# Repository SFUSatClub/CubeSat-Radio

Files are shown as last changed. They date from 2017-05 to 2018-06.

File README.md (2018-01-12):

# CubeSat-Radio
KiCad project of the cubesat radio test article in preparation for the Canadian Satellite Design Challenge

This repository uses the SFU Satellite Team's KiCad component library as a submodule.
To start working on the repository:

```
1. Open the git shell
2. Navigate to the directory you wish to place the repository inside
3. git clone --recursive "https://github.com/SFUSatClub/CubeSat-Radio.git"
4. cd .\CubeSat-Radio\KiCad-Lib\
5. git checkout master
```

If you modify either the component schematic or footprint libraries you must push those changes to the SFUSatClub/KiCad-Lib repository.

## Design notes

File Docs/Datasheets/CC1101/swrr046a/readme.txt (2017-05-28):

   
XXXXXXXXXXXXXXXXXXXXXXXXXXXXXXXXXXXXXXXXXXXXXXXXXXXXXXXXXXXXXXXXXXXXXXXXXXXXX
X                                                                           X
X   Artwork and documentation done by: Texas Instrument                     X
X                                                                           X
X   Company: Texas Instrument Norway Gaustadalleen 21    0349 OSLO          X
X                                                                           X
X   Phone  : +47 22 95 85 44   Fax :  +47 22 95 85 46                       X
X                                                                           X
X                                                                           X
XXXXXXXXXXXXXXXXXXXXXXXXXXXXXXXXXXXXXXXXXXXXXXXXXXXXXXXXXXXXXXXXXXXXXXXXXXXXX

PROJECT : 02552
PCB NAME : CC1101EM 434MHz
REVISION: 2.0.0 (schematic rev 2.0.0, PCB rev 2.0.0)
DATE: 2010-02-15

Manufacturers marking: Two letter + year + week
The two letter code shall identify the manufaturer and is decided by the manufacturer. 
No logos or other identifyers are allowed.
The marking shall be in silk screen print at secondary side of the PCB, or in solder 
resist if no silk print at secondary side.

FILE: CC1101EM_434MHz_2_0_0.ZIP PACKED WITH WinZIP 

PCB DESCRIPTION: 2 LAYER PCB 0.8 MM NOMINAL THICKNESS FR4
		Dimensions in mil (0.001 inch)
                            DOUBLE SIDE SOLDER MASK,
                            DOUBLE SIDE SILKSCREEN,
                            8 MIL MIN TRACE WIDTH AND 8 MIL MIN ISOLATION
		Dielectric constant for FR4 is 4.5

FILE NAME            		DESCRIPTION                               	FILE TYPE
-------------------------------------------------------------------------------------------
***PCB MANUFACTURING FILES:
l1.SPL                  LAYER 1 COMPONENT SIDE/POSITIV              EXT. GERBER
l2.SPL                  LAYER 2 Inner layer/POSITIV                 EXT. GERBER

STOPCOMP.SPL            SOLDER MASK COMPONENT SIDE/NEGATIVE         EXT. GERBER
STOPSOLD.SPL            SOLDER MASK SOLDER SIDE/NEGATIVE            EXT. GERBER

SILKCOMP.SPL            SILKSCREEN COMPONENT SIDE/POSITIVE          EXT. GERBER
SILKSOLD.SPL            SILKSCREEN SOLDER SIDE/POSITIVE             EXT. GERBER

PASTCOMP.SPL            SOLDER PAST COMPONENT SIDE/POSITIVE         EXT. GERBER
PATSOLD.SPL             SOLDER PAST SOLDER SIDE/POSITIVE            EXT. GERBER

ASSYCOMP.SPL            ASSEMBLY DRAWING COMPONENT SIDE					    EXT. GERBER
ASSYSOLD.SPL            ASSEMBLY DRAWING SOLDER SIDE				|       EXT. GERBER

NCDRILL.SPL             NC DRILL THROUGH HOLE                       EXCELLON
DRILL.SPL               DRILL/MECHANICAL DRAWING                    EXT. GERBER

GERBER.REP              DRILL/NC DRILL REPORT                       ASCII

P&PCOMP.REP             PICK AND PLACE FILE COMPONENT SIDE          ASCII
P&PSOLD.REP             PICK AND PLACE FILE SOLDER SIDE             ASCII

EXT_GERBER.USR          EXTENDED GERBER APERTURE TABLE              ASCII
CNC.USR                 NC DRILL DEVICE FILE                        ASCII

CC1100EM_868_915MHz_PARTLIST_2_0_0.xls		PART LIST									ASCII

***PDF FILES:
CC1101EM_868_915MHz_SCHEMATIC_2_0_0.PDF	Circuit Diagram
CC1101EM_868_915MHz_LAYOUT_2_0_0.PDF		Layout Diagram

***CADSTAR FILES:
CC1101EM_868_915MHz_2_0_0.SCM			Cadstar Schematic file
CC1101EM_868_915MHz_2_0_0.CSA			Cadstar Shematic archive
CC1101EM_868_915MHz_2_0_0.PCB			Cadstar Layout file
CC1101EM_868_915MHz_2_0_0.CPA			Cadstar PCB archive

README.TXT              THIS FILE                                   ASCII

***REVISION HISTORY

Changes from rev 1.0 to 2.0.0: 
	Crystal X1 changed to size 3.2x2.5 mm (NX3225GA)
	Changed crystal loading capacitors C81 and C101 to 12 pF and 15 pF respectively

END.

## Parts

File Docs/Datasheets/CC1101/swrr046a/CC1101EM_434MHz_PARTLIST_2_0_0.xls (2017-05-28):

CC1101EM 434 MHz Partlist 2.0.0
This list is automatically linked up to the G:\06_TEKNISK\06H_Cadstar\purchase_library\PurchaseLib.xls
Enter columns in green
Ref. | Part name | Pcs/unit | Description | Manufacturer | Part number | Supplier | Ordering code | Alt. Manufacturer | Alt. Part number | Alt. Supplier | Alt. Ordering code | Comments
U1 | CC1101 | 1 | Single-chip transceiver | TI | CC1101 | TI | CC1101 |  |  |  |  | Supplied by Chipcon
C41;C51 | C_100N_0402_X5R_K_10 | 2 | Capacitor, 100n, 0402, X5R, 10%, 10V | Murata | GRM155R71A104KA01D
C91;C141 | C_10N_0402_X7R_K_25 | 2 | Capacitor, 10n, 0402, X7R, 10%, 25V | Murata | GRM155R71E103KA01D
C81 | C_12P_0402_NP0_J_50 | 1 | Capacitor, 12p, 0402, NP0, 5%, 50V | Murata | GRM1555C1H120JZ01D
C101 | C_15P_0402_NP0_J_50 | 1 | Capacitor, 15p, 0402, NP0, 5%, 50V | Murata | GRM1555C1H150JZ01D
C1 | C_1U_0805_X7R_K_16 | 1 | Capacitor, 1u, 0805, X7R, 10%, 16V | Murata | GRM21BR71C105KA01L | ELFA | 65-809-71
C111;C124-125;C151;C181 | C_220P_0402_NP0_J_50 | 5 | Capacitor, 220p, 0402, NP0, 5%, 50V | Murata | GRM1555C1H221JA01D
C121;C131 | C_3P9_0402_NP0_C_50 | 2 | Capacitor, 3p9, 0402, NP0, +-0.25pF, 50V | Murata | GRM1555C1H3R9CZ01D
C123 | C_5P6_0402_NP0_C_50 | 1 | Capacitor, 5p6, 0402, NP0, +-0.25pF, 50V | Murata | GRM1555C1H5R6CZ01D
C122 | C_8P2_0402_NP0_C_50 | 1 | Capacitor, 8p2, 0402, NP0, +-0.25pF, 50V | Murata | GRM1555C1H8R2CZ01D
L122 | L_22N_0402_J | 1 | Inductor, 22n, 0402, ±5% | Murata | LQG15HS22NJ02D | ACTE
L121;L123;L131 | L_27N_0402_J | 3 | Inductor, 27n, 0402, ±5% | Murata | LQG15HS27NJ02D | ACTE
L1 | L_BEAD_102_0402 | 1 | EMI filter bead, 0402 1Kohms Tape GHz Band Gen Use | Murata | BLM15HG102SN1D | ACTE
R171 | R_56K_0402_F | 1 | Resistor, 56k ohms, 0402, ±1% | Koa | RK73H1ETTP5602F | ELFA | 60-488-96
P3 | SMA_SMD | 1 | SMA connector, straight SMD-mount | Hus-Tsan Group Taiwan | SMA-10V21-TGG | EC Partner A/S | SMA-10V21-TGG
P1-2 | SMD_SOCKET_2x10 | 2 | SMD pinrow socket, .050 spacing, 2x10 | Samtec | SFM-110-02-SM-D-A-K-TR | Abacus
X1 | X_26.000/20/40/40/10 | 1 | Crystal, 26.000000MHz, 10.0pF, 50 ohms max, 20/40 ppm, -40C to +85C | NDK | NX3225GA, EXS00A-CG01972 | NDK | NX3225GA, EXS00A-CG01972
 |  | 27

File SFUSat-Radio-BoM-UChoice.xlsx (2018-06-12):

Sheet: SFUSat-Radio
Reference | Value | Footprint | Datasheet | Part Number | Digi-Key | Mouser | Digikey | Categories | Composition | Failure Rate | Features | Height - Seated (Max) | Lead Free Status / RoHS Status | Manufacturer 1 | Manufacturer Part Number 1 | Manufacturer Standard Lead Time 1 | Number of Terminations | Package / Case | Part Status | Power (Watts) | Resistance | Series | Size / Dimension | Supplier 1 | Supplier Device Package | Supplier Part Number 1 | Temperature Coefficient | Tolerance | Circuit | Frequency - Lower | Frequency - Upper | IIP3 | Impedance | Insertion Loss @ Frequency | Isolation @ Frequency | Operating Temperature | P1dB | RF Type | Topology | Voltage - Supply | Base Part Number | Current - Output High | Low | Independent Circuits | Mounting Type | Type | Voltage Supply Source | Applications | Capacitance | Lead Spacing | Lead Style | Ratings | Thickness (Max) | Voltage - Rated | Current Rating | DC Resistance (DCR) | Frequency - Self Resonant | Frequency - Test | Inductance
J1 | PC104-8BIT | SFUSat:PC104-8bit
J4 | PC104PTH | SFUSat:PC104PTH
J5 | PC104PTH | SFUSat:PC104PTH
J3 | PC104PTH | SFUSat:PC104PTH
J2 | PC104PTH | SFUSat:PC104PTH
C415 | DNP | SFUSat:C_0402
U1 | SINGLE_0402 | SFUSat:SINGLE_0402
U500 | SINGLE_0402 | SFUSat:SINGLE_0402
U400 | SINGLE_0402 | SFUSat:SINGLE_0402
R604 | DNP | SFUSat-res:R_0402
L503 | DNP | SFUSat-ind:L_0603
R2 | 1k0-DNP | SFUSat-res:R_0402 |  |  |  |  |  | Resistors - Chip Resistor - Surface Mount | Thin Film | - | Automotive AEC-Q200 | 0.016" (0.40mm) | Lead free / RoHS Compliant | Panasonic Electronic Components | ERA-2AED102X | 23 Weeks | 2 | 0402 (1005 Metric) | Active | 0.063W, 1/16W | 1 kOhms | ERA-2A | 0.039" L x 0.020" W (1.00mm x 0.50mm) | Digi-Key | 402 | P1.0KDECT-ND | ±25ppm/°C | ±0.5% |  |  |  |  |  |  |  | -55°C ~ 155°C
R1 | 1k0-DNP | SFUSat-res:R_0402 |  |  |  |  |  | Resistors - Chip Resistor - Surface Mount | Thin Film | - | Automotive AEC-Q200 | 0.016" (0.40mm) | Lead free / RoHS Compliant | Panasonic Electronic Components | ERA-2AED102X | 23 Weeks | 2 | 0402 (1005 Metric) | Active | 0.063W, 1/16W | 1 kOhms | ERA-2A | 0.039" L x 0.020" W (1.00mm x 0.50mm) | Digi-Key | 402 | P1.0KDECT-ND | ±25ppm/°C | ±0.5% |  |  |  |  |  |  |  | -55°C ~ 155°C
C416 | DNP | SFUSat:C_0402
C519 | DNP | SFUSat:C_0402
J15 | Conn_01x02 | SFUSat:Socket_Strip_Straight_1x02_Pitch2.54mm
J25 | Conn_01x02 | SFUSat:Socket_Strip_Straight_1x02_Pitch2.54mm
J7 | TP_TH_150 | SFUSat:TP_TH_150
J8 | TP_TH_150 | SFUSat:TP_TH_150
J9 | TP_TH_150 | SFUSat:TP_TH_150
J10 | TP_TH_150 | SFUSat:TP_TH_150
J11 | TP_TH_150 | SFUSat:TP_TH_150
C529 | DNP | SFUSat:C_0402
C429 | DNP | SFUSat:C_0402
C530 | DNP | SFUSat:C_0402
C531 | DNP | SFUSat:C_0402
C532 | DNP | SFUSat:C_0402
C533 | DNP | SFUSat:C_0402
C534 | DNP | SFUSat:C_0402
C430 | DNP | SFUSat:C_0402
C431 | DNP | SFUSat:C_0402
C432 | DNP | SFUSat:C_0402
C433 | DNP | SFUSat:C_0402
C434 | DNP | SFUSat:C_0402
 |  |  |  | RC0402FR-071K21L | 311-1.21KLRCT-ND | 603-RC0402FR-071K21L
U6 | SINGLE_0402 | SFUSat:SINGLE_0402
C411 | DNP | SFUSat:C_0402 |  | GRM155R61A105KE15D | 490-12701-1-ND | 81-GRM155R61A105KE1D
C427 | DNP | SFUSat:C_0402
C426 | DNP | SFUSat:C_0402
C425 | DNP | SFUSat:C_0402
C424 | DNP | SFUSat:C_0402
C423 | DNP | SFUSat:C_0402
C428 | DNP | SFUSat:C_0402
J401 | TP_TH_150 | SFUSat:TP_TH_150
J402 | TP_TH_150 | SFUSat:TP_TH_150
J404 | TP_TH_150 | SFUSat:TP_TH_150
J405 | TP_TH_150 | SFUSat:TP_TH_150
J406 | TP_TH_150 | SFUSat:TP_TH_150
R411 | DNP | SFUSat-res:R_0805
C511 | DNP | SFUSat:C_0402 |  | GRM155R61A105KE15D | 490-12701-1-ND | 81-GRM155R61A105KE1D
C527 | DNP | SFUSat:C_0402
C526 | DNP | SFUSat:C_0402
C525 | DNP | SFUSat:C_0402
C524 | DNP | SFUSat:C_0402
C523 | DNP | SFUSat:C_0402
C528 | DNP | SFUSat:C_0402
J501 | TP_TH_150 | SFUSat:TP_TH_150
J502 | TP_TH_150 | SFUSat:TP_TH_150
J504 | TP_TH_150 | SFUSat:TP_TH_150
J505 | TP_TH_150 | SFUSat:TP_TH_150
J506 | TP_TH_150 | SFUSat:TP_TH_150
R511 | DNP | SFUSat-res:R_0805
U8 | SINGLE_0402 | SFUSat:SINGLE_0402
U11 | SINGLE_0402 | SFUSat:SINGLE_0402
C600 | DNP | SFUSat-cap:C_0402
J22 | TP_TH_150 | SFUSat:TP_TH_150
J21 | TP_TH_150 | SFUSat:TP_TH_150
J24 | TP_TH_150 | SFUSat:TP_TH_150
J23 | TP_TH_150 | SFUSat:TP_TH_150
C610 | DNP | SFUSat-cap:C_0402
C34 | DNP | SFUSat:C_0402

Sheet: Sheet2
Ref | Value | Footprint | Man PN | Digikey | Mouser | Descr | quant
D3, D11, D1, D420, D421, D2, D4 | GREEN | SFUSat:LED_0603 | LTST-C191KGKT | 160-1446-1-ND (http://www.digikey.ca/products/en?keywords=160-1446-1-ND) |  |  | 7
R3, R13, R18, R420, R421, R8, R14 | 287 | SFUSat:R_0402 | ERJ-2RKF2870X | P287LCT-ND (http://www.digikey.ca/products/en?keywords=P287LCT-ND) |  |  | 7
C517, C417, C420 | 10pF | SFUSat-cap:C_0402 | GJM1555C1H100JB01D | 490-3113-1-ND |  | Capacitors - Ceramic Capacitors | 3
L402, L403, L401, L405 | 0R0 | SFUSat:L_0603 | RMC1/16JPTP | N/A | 791-RMC1/16JPTP |  | 4
U101 | 0433BM15A0001 | SFUSat:U_0805-6 | 0433BM15A0001E | 712-1540-1-ND | 609-0433BM15A0001E |  | 1
U111 | 0915BM15A0001E | SFUSat:U_0805-6 | 0915BM15A0001E |  | 609-0915BM15A0001E |  | 1
J12, J14, J13, J18, J17, J500, J400, J16 | SMA | SFUSat:UFL-R-SMT-1-Coaxial-Connector | U.FL-R-SMT(01) | H9161-ND |  |  | 8
C414 | 22pF | SFUSat:C_0402 | GRM1555C1H220JZ01E | 490-11382-1-ND | 81-GRM1555C1H220JA1J |  | 1
L400 | 8.2nH | SFUSat:L_0402 | 0402CS-8N2XJLW | N/A | 994-0402CS-8N2XJLW |  | 1
C421 | 1.2pF | SFUSat:C_0402 | GJM1555C1H1R2BB01D | 490-8085-1-ND | 81-GJM1555C1H1R2BB01 |  | 1
L404 | 12.55nH | SFUSat-ind:L_1606 | 1606-10J | N/A | 994-1606-6JLC |  | 1
R605, R615, R612, R611, R600, R603 | 0R | SFUSat-res:R_0402 | AC0402JR-070RL | 311-0.0LBCT-ND |  |  | 6
U2 | SKY13345-368LF | SFUSat:12-UFQFN-PAD | SKY13345-368LF | 863-1450-1-ND |  |  | 1
U3 | CD4555BPWR | SFUSat:TSSOP-16 | CD4555BPWR | 296-31540-1-ND |  |  | 1
C515, C102, C112 | 15pF | SFUSat-cap:C_0402 | GJM1555C1H150JB01D | 490-3117-1-ND |  |  | 3
C516, C101, C111 | 12pF | SFUSat-cap:C_0402 | GJM1555C1H120JB01D | 490-3115-1-ND |  |  | 3
C518, C41 | 27pF | SFUSat-cap:C_0402 | GRM1555C1H270JA01D | 490-5869-1-ND |  |  | 2
L505 | 1.5nH | SFUSat-ind:L_0603 | LQG18HN1N5S00D | 490-1100-1-ND |  |  | 1
C520 | 5.6pF | SFUSat-cap:C_0402 | GJM1555C1H5R6CB01D | 490-3103-1-ND |  |  | 1
C521 | 0.5pF | SFUSat-cap:C_0402 | GJM1555C1HR50CB01D | 490-3081-1-ND |  |  | 1
C522, C513, C413, C422 | 39pF | SFUSat-cap:C_0402 | GRM1555C1H390JA01D | 490-5871-1-ND |  |  | 4
C514 | 7.5pF | SFUSat-cap:C_0402 | GRM1555C1H7R5BA01D | 490-8227-1-ND |  |  | 1
L502, L501 | 220R | SFUSat-ind:L_0603 | BLM18EG221SN1D | 490-3992-1-ND |  |  | 2
L504 | 5.6nH | SFUSat-ind:L_1606 | 1606-6JLC |  | 994-1606-6JLC |  | 1
L500 | 2.7nH | SFUSat-ind:L_0402 | 0402CS-2N7XJLW |  | 994-0402CS-2N7XJLW |  | 1
C42, C41, C106, C105, C103, C107, C100, C116, C115, C113, C117, C110, C25, C33, C10 | 100nF | SFUSat-cap:C_0402 | CGA2B1X7R1C104M050BC |  | 445-12242-1-ND |  | 15
C11, C3 | 100pF | SFUSat:C_0402 | GRM1555C1H101JA01D | 490-5922-1-ND | 81-GRM1555C1H101JA1D |  | 2
L3 | 24nH | SFUSat:L_0402 | 0402CS-24NXGLW | N/A | 994-0402CS-24NXGLW |  | 1
C9, C4 | 390pF | SFUSat:C_0402 | GRM1555C1H391JA01J | 490-6236-1-ND | 81-GRM1555C1H391JA1J |  | 2
C7, C8 | 56pF | SFUSat:C_0402 | GRM1555C1H560JA01D | 490-1288-1-ND | 81-GRM1555C1H560JA1D |  | 2
C5, C6, C39 | 0.01uF | SFUSat:C_0402 | GRM155R71E103KA01D | 490-1312-1-ND | 81-GRM36X103K25 |  | 3
U5 | MML09211H | SFUSat:8-VFDFN | MML09211HT1 | MML09211HT1CT-ND | 841-MML09211HT1 |  | 1
L2 | 4.3nH | SFUSat:L_0402 | 0402CS-4N3XGLW | N/A | 994-0402CS-4N3XGLW |  | 1
L1 | 22nH | SFUSat:L_0402 | 0402CS-22NXGLW | N/A | 994-0402CS-22NXGLW |  | 1
C404, C410, C504, C510, C35, C418 | 2.2uF | SFUSat:C_0402 | JMK105BJ225MVHF | 587-3710-1-ND | 963-JMK105BJ225MVHF |  | 6
U16 | TPS71750DSER | SFUSat:WSON-6 | TPS71750DSER | 296-25361-1-ND |  |  | 1
C37 | 22uF | SFUSat-cap:C_1206 | GRM31CR61A226ME19L | 490-4738-1-ND |  |  | 1
R410, R510, R15 | 100k | SFUSat-res:R_0805 | ERJ-6ENF1003V | P100KCCT-ND |  |  | 3
R17 | 383k | SFUSat-res:R_0402 | CRCW0402383KFKED | 541-383KLCT-ND |  |  | 1
R16 | 2.37M | SFUSat-res:R_0402 | CRCW04022M37FKED | 541-2.37MLCT-ND |  |  | 1
L4 | 10uH | SFUSat-ind:SLF6045 | SLF6045T-100M1R6-3PF | 445-4573-1-ND |  |  | 1
L5 | 10uH | SFUSat-ind:SLF7045 | SLF7045T-100M1R3-PF | 445-2014-1-ND |  |  | 1
C36 | 2.2uF | SFUSat-cap:C_0805 | GRM21BR71A225KA01L | 490-1696-1-ND |  |  | 1
U15 | TPS62175DQCR | SFUSat:WSON-10 | TPS62175DQCR | 296-39451-1-ND |  |  | 1
R504, R11, R12, R404, R6 | 1K | SFUSat:R_0402 | RC0402JR-071KL | 311-1.0KJRCT-ND | 603-RC0402JR-071KL |  | 5
U10 | TPS799 | SFUSat:PDSO-G5 | TPS79933DDCR | 296-17783-1-ND | 595-TPS79933DDCR |  | 1
C407, C40, C408, C409, C402, C507, C508, C509, C502, C32, C31 | 1uF | SFUSat:C_0402 | GRM155R61A105KE01D | 490-12701-1-ND | 81-GRM155R61A105KE1D |  | 11
U9 | TLV702 | SFUSat:SOT_23_5 | TLV70231DBVT | 296-27894-1-ND | 595-TLV70231DBVT |  | 1
U4 | LMS3635AQRNLRQ1 | SFUSat:LMS3635AQRNLTQ1 | 595-LMS3635AQRNLTQ1 | 296-47482-1-ND |  |  | 1
C30, C26, C27, C28, C29 | 47uF | SFUSat-cap:C_1206 | GRM31CR60J476KE19L | 490-6508-1-ND |  |  | 5
C401, C412, C501, C512 | 10uF | SFUSat-cap:C_TANT_1411 | TAJB106K016RNJ | 478-1673-1-ND |  |  | 4
C503, C40 | 10uF | SFUSat-cap:C_TANT_2312 | TAJC106M025RNJ | 478-3896-1-ND |  |  | 2
C16, C2, C1, C20, C19, C18 | 10uF | SFUSat-cap:C_1210 | EMK325BJ106KN-T | 587-1376-1-ND |  |  | 6
C21, C17 | 1nF | SFUSat-cap:C_0402 | GRM155R61C102KA01D | 490-6308-1-ND |  |  | 2
R4 | 49k9 | SFUSat-res:R_0805 | ERJ-6ENF4992V | P49.9KCCT-ND |  |  | 1
R9 | 19K1 | SFUSat-res:R_0805 | ERJ-6ENF1912V | P19.1KCCT-ND |  |  | 1
R10 | 3.01R | SFUSat-res:R_0402 | CRCW04023R01FKED | 541-3.01LLCT-ND |  |  | 1
C22 | 4.7uF | SFUSat-cap:C_0805 | GRM219R61A475KE34D | 490-3339-1-ND |  |  | 1
C24 | 680pF | SFUSat-cap:C_0402 | GRM1555C1E681JA01D | 490-6182-1-ND |  |  | 1
C23 | 470nF | SFUSat-cap:C_0402 | GRM155R60J474KE19D | 490-3266-1-ND |  |  | 1
U600, U610 | STLM75 | SFUSat:TSSOP-8-3x3mm-SOT505-1 | STLM75DS2F | 497-6326-1-ND |  |  | 2
U420, U1 | 2N7002DW | SFUSat:SOT-363 | 2N7002DW-7-F | 2N7002DW-FDICT-ND (http://www.digikey.ca/products/en?keywords=2N7002DW-FDICT-ND) |  |  | 2
C506, C104, C114, C406 | 220pF | SFUSat:C_0402 | GRM1555C1H221JA01E | 490-1293-1-ND | 81-GRM1555C1H221JA01 |  | 4
R502, R503, R402, R403 | 390R | SFUSat:R_0402 | RMC1/16S-391JTH | N/A | 791-RMC1/16S-391JTH |  | 4
U402, U502 | RF6886 | SFUSat:QFN-24 | RF6886TR13 | 689-1091-1-ND | 772-RF6886 |  | 2
C405, C505 | 0.33uF | SFUSat-cap:C_0402 | CL05A334KP5NNNC | 1276-6665-1-ND |  |  | 2
C12, C14, C15 | 47pF | SFUSat:C_0402 | GRM1555C1H470JA01D | 490-5942-1-ND (http://www.digikey.ca/products/en?keywords=490-5942-1-ND) |  |  | 3
R100, R110 | 56k | SFUSat:R_0402 | ERJ-2RKF5602X | P56.0KLCT-ND (http://www.digikey.ca/products/en?keywords=P56.0KLCT-ND) |  |  | 2
X110, X100 | NX3225GA | SFUSat:NX3225GA | NX3225GA-26MHZ-TI | 644-1160-1-ND |  |  | 2
U100, U110 | CC1101-Q1 | SFUSat:CC1101-Q1 | CC1101QRHBRG4Q1 | 296-24870-1-ND | 595-CC1101QRHBRG4Q1 |  | 2
U17 | 74LVC1G14SE-7 | SFUSat:SOT353 | 74LVC1G14SE-7 | 74LVC1G14SE-7CT-ND |  |  | 1
C13 | 47nF | SFUSat:C_0402 | GRM155R71E473KA88D | 490-3254-1-ND (http://www.digikey.ca/products/en?keywords=490-3254-1-ND) |  |  | 1
U7 | SKY13372-467LF | SFUSat:QFN-16_650P | SKY13372-467LF | 863-1645-1-ND (http://www.digikey.ca/products/en?keywords=863-1645-1-ND) |  |  | 1
R501,R509, R401, R409 | 220R | SFUSat:R_0402 | RMC1/16S-221JTH | N/A | 791-RMC1/16S-221JTH |  | 4
R405, R406, R407, R408, R505, R506, R507, R508 | 10K | SFUSat:R_0402 | RC0402JR-0710KL | 311-10KJRCT-ND | 603-RC0402JR-0710KL |  | 8
U501, U401 | LMV358 | SFUSat:TSSOP-8_4.4x3mm_Pitch0.65mm | LMV358IYDT | 497-10524-1-ND | 511-LMV358IYDT |  | 2
R5 | 0R05 | SFUSat:C_0603 | BLM18EG221SN1D | 490-3992-1-ND | 81-BLM18EG221SN1D |  | 1
R7 | 100 | SFUSat:R_0402 | RC0402FR-07100RL | 311-100LRCT-ND | 603-RC0402FR-07100RL |  | 1
P1 | 3pin-DC-power | SFUSat:PJ-028-SMT-TR-3pin-DC-jack | PJ-028-SMT-TR | CP-028PJCT-ND |  |  | 1
SH400, SH500 | BMI-S-205-F | SFUSat:BMI-S-205-F | BMI-S-205-F | 903-1054-1-ND |  |  | 2
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

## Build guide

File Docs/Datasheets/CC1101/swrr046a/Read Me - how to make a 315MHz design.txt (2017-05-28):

Dear Valued Customer,

The hardware layout of the reference design in this ZIP file is designed for both 315 MHz and 433MHz operation. The only difference between the two designs is the component values related to the RF layout.

If you are making a 315MHz design, please use the following bill of material (BOM) for optimum RF performance:

BOM CC1101EM 315MHz Reference Design

C_100N_0402_X5R_K_10           C41
C_100N_0402_X5R_K_10           C51
C_10N_0402_X7R_K_25            C111
C_10N_0402_X7R_K_25            C91
C_10N_0402_X7R_K_25            C141
C_12P_0402_NP0_J_50            C122
C_1U_0805_X7R_K_16             C1
C_220P_0402_NP0_J_50           C181
C_220P_0402_NP0_J_50           C125
C_220P_0402_NP0_J_50           C151
C_220P_0402_NP0_J_50           C124
C_12P_0402_NP0_J_50            C81
C_15P_0402_NP0_J_50            C101
C_6P8_0402_NP0_J_50            C121
C_6P8_0402_NP0_J_50            C123
C_6P8_0402_NP0_J_50            C131
CC1100                         U1
L_18N_0402_J                   L122
L_33N_0402_J                   L131
L_33N_0402_J                   L123
L_33N_0402_J                   L121
L_BEAD_102_0402                L1
R_56K_0402_F                   R171
SMA_SMD                        P3
SMD_SOCKET_2x10                P2
SMD_SOCKET_2x10                P1
X_26.000/50/10           			 X1

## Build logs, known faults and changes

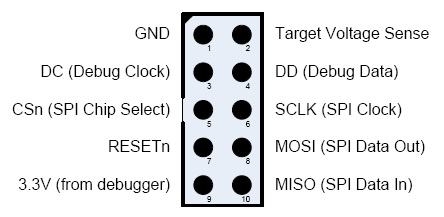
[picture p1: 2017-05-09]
Docs/CC-Debugger-Header.jpg

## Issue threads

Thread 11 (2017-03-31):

Investigate issues with LEDs

TobiNakamura, 2017-03-31:

Closed 2017-04-20.

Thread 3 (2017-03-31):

Need ability to probe desired points in RF path

Alenux55, 2017-03-31:
Add a vertical SMA population option between CC1125 and balun, balun and switch, and switch and front end

Alenux55, 2017-03-31:
Also, make this a resistor population option, like a T-junction

TobiNakamura, 2017-05-25:
Can the T-junction be made such that the placement of SMA can be selected facing towards or away from the font of the signal chain? Should there be 2 SMA footprints at each node in the signal chain; one for each direction?

Alenux55, 2017-05-31:
Instead of one SMA for each direction, use a single 0402 SMA pad such that a jumper can be placed at 45 degrees in either direction:
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

TobiNakamura, 2017-06-10:
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
Too weird?

Alenux55, 2017-06-11:
What if we just make the rectangular pad into a square and rotate it 45 degrees?

Alenux55, 2017-06-11:
Lets move this to the issue in KiCad-Lib since the main objective of this issue is complete. [https://github.com/SFUSatClub/KiCad-Lib/issues/13](https://github.com/SFUSatClub/KiCad-Lib/issues/13)

Closed 2017-06-11.

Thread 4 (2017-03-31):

Adjust solder paste aperture sizes

Alenux55, 2017-03-31:
- Make passive apertures larger
- Make IC thermal aperture smaller

TobiNakamura, 2017-05-30:
See KiCad-Lib for fixes. Have yet to make IC thermal aperture smaller

TobiNakamura, 2017-05-31:
Made SKY65366 thermal pad aperture smaller

Alenux55, 2017-06-11:
Do we want to move this to KiCad-Lib issues?

TobiNakamura, 2017-06-11:
Yes but i can also be closed so...

Closed 2017-06-11.

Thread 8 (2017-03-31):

Double check connectors

Alenux55, 2017-03-31:

Alenux55, 2017-05-31:
This is too vague, and not particularly relevant considering we're making a new board anyway

Closed 2017-05-31.

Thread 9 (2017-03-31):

Incorporate connector ESD connection

Alenux55, 2017-03-31:

TobiNakamura, 2017-05-18:
Also for tactile switches and toggle switches and any other exposed interfaces

TobiNakamura, 2017-06-10:
No ESD protection on CC debug connector or PC104 connector due to large number of pins. ESD suppression was placed on test points, jumpers, and potentiometers. 2d7826e3472c9caad9861fabc356ae1afd1395ca

Alenux55, 2017-06-11:
- Are we relying on the LDOs as ESD protection from Vin?
- Do we need D10 if we have D9?

TobiNakamura, 2017-06-11:
Vin is 5V, the knee of the TVS diodes are 5V or so. Yes, too cheap to get another TVS diodes, the LDO can burn. TVS should be on SKY input and on POT to protect 3v3 line.

Alenux55, 2017-06-11:
Gotcha, because **R7** is close to **RV1**:
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

And then none on **R8** because it's far from the jumper. Do we want any extra protection on P4 as it's attached to the debugger?

TobiNakamura, 2017-06-11:
TVS diode added OP_3v3. 39e230a1014d43e301bcf52a7b34e85acb464f90

Closed 2017-06-12.

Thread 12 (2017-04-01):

Fix switch for PA/LNA bypass

Alenux55, 2017-04-01:

Alenux55, 2017-06-02:
This switched has been removed in Rev 2. Closed.

Closed 2017-06-02.

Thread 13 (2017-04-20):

2N7002DW pin assignment incorrect

TobiNakamura, 2017-04-20:
Component pin assignment is incorrect. Please read datasheet https://www.diodes.com/assets/Datasheets/ds30120.pdf

TX and 3V6 indicator LEDs do not work because of this.

TobiNakamura, 2017-05-26:
Fixed, please review

liquiddandruff, 2017-05-26:
Can also paste commit hash to reference the commit too ;)  e4fd6992

Alenux55, 2017-05-31:
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
Part is mirrored. Please update symbol and make footprint mapping as follows:
6  5  4
1  2  3

TobiNakamura, 2017-05-31:
ef6c72adf7fbf4c4be107657a5a16833a87c14b3

Alenux55, 2017-05-31:
Checked, looks good
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

Closed 2017-05-31.

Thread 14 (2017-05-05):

Reset push button and LED

TobiNakamura, 2017-05-05:
push button and indicator LED on RESETn pin

TobiNakamura, 2017-05-31:
no reset line, this issue is irrelevent

Closed 2017-05-31.

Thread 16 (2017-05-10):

IC pad separation must be 30 mil

TobiNakamura, 2017-05-10:
IC pads and passive component pads must be separated by  a minimum of 30 mils. This is to prevent solder from spilling off the IC pad and pulling the passive component in.

TobiNakamura, 2017-06-10:
a40c3216503376dc765c6250f1140a7c116a8822

Closed 2017-06-10.

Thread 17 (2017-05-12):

Flip the signals on the debugger connector (P1)

Alenux55, 2017-05-12:

TobiNakamura, 2017-05-26:
Follow the CC debugger datasheet.
Done, please review then close

TobiNakamura, 2017-05-31:
connector layout and schematic connection reviewed

Closed 2017-05-31.

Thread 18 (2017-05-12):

Replace CC1125 with CC1101

Alenux55, 2017-05-12:

TobiNakamura, 2017-05-31:
reviewed schematic connection for CC1101 and balun.
Reviewed component values of CC1101.
Reviewed debugger connection with CC1101.
Reviewed footprint, aperture, stop mask of CC1101 and balun.

Closed 2017-05-31.

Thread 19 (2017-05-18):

Add reverse polarity protection

TobiNakamura, 2017-05-18:
P-Fet on high side input

TobiNakamura, 2017-06-10:
No convenient place to put a FET for reverse polarity protection. Because of connector layout it is difficult to connect DC accidentally in reverse.

Closed 2017-06-10.

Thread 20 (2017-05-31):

Move POT for VPC control to ground, fixed resistor to 3v3

TobiNakamura, 2017-05-31:
Fixed resistor should be 3.2K, POT will be the same one used for Rev_1.
This way turning the POT full way will result in 2.5V or 0V.
Considered 50K pull down present in SKY65366-21 for calculation.

TobiNakamura, 2017-06-07:
764d84e27edea83bda7cb37d0cbc6eef1bb36361

Alenux55, 2017-06-07:
Potentiometer is 10 kΩ, so from the [datasheet](http://www.bourns.com/docs/Product-Datasheets/TC33.pdf), the minimum resistance is **200 Ω**:
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

So we have:
_Vout,max = [(3.3 V)*(10000)]/[(3200+10000)] = **2.5 V**_
_Vout,min = [(3.3 V)*(200)]/[(3200+200)] = **0.2 V**_

Looks good. I doubt we'll need true **0 V** considering this is for the PA (will most likely want that value high)

Closed 2017-06-07.

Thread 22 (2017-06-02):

Check PC104 layout

TobiNakamura, 2017-06-02:
Check board size, mechanical hole size, plating, position, connector position.

Alenux55, 2017-06-02:
Comments:
-Board size is good
-Hole size, plating, and position is good
-Connector position looks good
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

Closed 2017-06-02.

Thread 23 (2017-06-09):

Check Connector Labeling

TobiNakamura, 2017-06-09:
Check labels on jumpers, SMA connectors, PC/104 connector, test points.
I forgot to label the LEDs.

TobiNakamura, 2017-06-09:
938609b44109fadba14369935545f2254597ae9c

Alenux55, 2017-06-09:
- **W3** looks good on the **3.6 V** line
- **P3** looks good
    - Can we shorten the silkscreen from _AMP EN_ to _EN_? I think the text above the part conveys that it controls the amplifier
- **W2** looks good, but wouldn't it be better to connect to the center pin of P2 so we can check VPC from either source?
- **P2** looks good

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

- **P4** looks good
- **W4** looks good
- **W1** looks good
    - Need to make sure we can configure GPIO2 of CC1101 to do this (see **table 41** setting **0x1C** in the datasheet for candidate; active low signal, active for **SLEEP** and **RX** states)

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

- **J8** looks good
- **J9** looks good

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

TobiNakamura, 2017-06-10:
7a60c29a94ea7f9e260f3175538d6a2e0feaa4c7

Alenux55, 2017-06-11:
Requested changes look good, closing
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

Closed 2017-06-11.

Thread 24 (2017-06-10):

Check Ground plane

TobiNakamura, 2017-06-10:
Pay attention to copper islands.
Pay attention to return current paths especially for VCC_* and microstrip.

Alenux55, 2017-06-14:
I'm a bit concerned about the possibility for acid traps with all the thermals:
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

TobiNakamura, 2017-06-14:
All ICs and some passives have been flooded.

Closed 2017-06-14.

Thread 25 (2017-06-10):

Check RF path

TobiNakamura, 2017-06-10:
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
Check CPWG, passives, wall of ground vias.

TobiNakamura, 2017-06-10:
The substrait thickness is not 0.2mm, its 1.6mm.
The track width is a bit worrisome.
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

TobiNakamura, 2017-06-11:
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

TobiNakamura, 2017-06-13:
PCBWay confirmed that Dk is 3.8.
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

Alenux55, 2017-06-14:
Do we want to update the trace width to get it closer to **50 Ω**? At the current thickness, we'll get **52.5 Ω**

Alenux55, 2017-06-14:
Also, do we want to add fencing vias along the RF traces? According to [this document](www.edn.com/Pdf/ViewPdf?contentItemId=4406491), if the vias are spaced less than about **2 inches**, we won't run into ground impedance issues.

Further, from the same document:
_Spacing the ground vias at 1/8th of a wavelength gives good isolation here also, but for the ultimate
isolation available (i.e., greater than the 120 dB that a modern network analyzer can measure) it has
been found that the via spacing should be kept to 1/20th of a wavelength or less._

In our case, **1/20** of the wavelength is about **3.5 cm**, which is easily doable.

Alenux55, 2017-06-14:
Never mind about the via fencing

TobiNakamura, 2017-06-14:
RF traces are now 0.6mm width with 0.2mm spacing to ground.

Closed 2017-06-14.

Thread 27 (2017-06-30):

Flip PC104 connector pins

Alenux55, 2017-06-30:
Although the library component for the PC104 connector was updated, the change did not propagate to the RF board:
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
Row B should be on the left row B on the right.

richarthurs, 2017-07-07:
Fixed

richarthurs, 2017-07-07:
Updated component in library, needs to be changed on RF PCB

TobiNakamura, 2018-04-01:
PC/104 back plane rotated such that A side is closest to edge

Closed 2018-04-01.

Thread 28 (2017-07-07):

Reduce text thickness

TobiNakamura, 2017-07-07:
Reduce the text thickness on the silkscreen, not the component reference but the other miscellaneous labels. Currently the thickness makes the text blotchy.

TobiNakamura, 2018-04-01:
0.3mm thickness works well for crisp edges

Closed 2018-04-01.

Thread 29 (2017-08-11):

Add BOM information in KiCad

TobiNakamura, 2017-08-11:
Add digikey and mouser numbers to all components

Alenux55, 2018-04-04:
Most components have part numbers now, but the parameters are different (Manufacturer's Part Number vs. Part Number).

I'd like to update the BOM script to ignore unused fields and unused parts (DNP, mounting holes, etc.)

Closed 2018-04-26.

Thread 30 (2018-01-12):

Formalise Antenna Connection

TobiNakamura, 2018-01-12:
Confirm with Structural regarding placement of SMA connector

TobiNakamura, 2018-03-21:
Connector should go on the -x side of the board (opposite to PC/104 bus) and 2.5cm off from the center.
This placement will facilitate securing the cable to the board after the end plate has been put onto the cubesat via a small access panel. Tweezers with rubber tips will be required the screw the cable in.

Alenux55, 2018-03-30:
Please provide a coordinates for the SMA connector with respect to the PC104 connector

TobiNakamura, 2018-04-01:
SMA has been fixed to the required location on the board.

Alenux55, 2018-04-24:
@TobiNakamura can we close this issue?

Closed 2018-04-24.

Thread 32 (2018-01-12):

Look into U.FL connectors for RF test

Alenux55, 2018-01-12:
Assuming that we run out of space, we may need to go to a connector smaller than SMA for the test connectors

TobiNakamura, 2018-02-27:
The goal of RF test connectors is to:
1. observe the signal along various points in the signal chain
2. characterise subcircuits, requires isolating the subcircuit from the signal chain.

Closed 2018-03-05.

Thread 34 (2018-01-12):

Power Supply Architecture

TobiNakamura, 2018-01-12:
The comms module requires a high current 3.6V rail and low current 3.3V, 3.1V rails. All of these rails requires good noise isolation from the rest of the spacecraft (specifically the switching regulators that generates the parent rails). The system architecture must be agreed upon for the entire spacecraft before we can proceed.

TobiNakamura, 2018-04-01:
See Mark 3 folder in RF google drive for power supply architecture

Closed 2018-04-01.

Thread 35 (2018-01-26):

RF6886 Vreg Range Unknown

TobiNakamura, 2018-01-26:
In Amp_dev we assumed Vreg had a maximum value of 3.1V but LOG10(ref-sense) vs Pout graph states full scale 3.2V for Vreg. Add a pot so that we can control the positive rail fed to the opamps

TobiNakamura, 2018-04-26:
The PA seems to output near the full 2 Watts as expected using the current configuration with 3.1v

Closed 2018-04-26.

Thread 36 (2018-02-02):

Integrating capacitor on the second op-amp of PA feedback

TobiNakamura, 2018-02-02:
Use 0603 cap, minimum value 0.2uF.

Minimum capacitance value was determined with power setting (pot) set to 0 and input at 10dbm.

TobiNakamura, 2018-04-27:
using 0402 0.33uf cap

Closed 2018-04-27.

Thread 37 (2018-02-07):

RBF Switch

TobiNakamura, 2018-02-07:
Not enough space on the computing board for the roller switch. Will need to go on the RF board due to access panel requirements.

TobiNakamura, 2018-04-01:
All RBFs have been moved to the eps board

Closed 2018-04-01.

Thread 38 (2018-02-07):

Add temperature sensor

TobiNakamura, 2018-02-07:
Add I2C SMT temp. sensor. Add information onto the systems spreadsheet.

TobiNakamura, 2018-03-05:
added 2, one for UB, one for LB power amplifier

Closed 2018-03-05.

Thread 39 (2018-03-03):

RF Switching

TobiNakamura, 2018-03-03:
Currently a the architecture is
antenna --- diplexer --- Switch --- PA
                        |                  |
                Upper band     LNA

This introduced ~0.5db of attenuation at the diplexer and a further 0.5db at the switch. If we eliminate the switch and use a SP4T RF switch we can reduce the total loss to 0.5db

http://www.skyworksinc.com/uploads/documents/SKY13388_465LF_201403H.pdf

TobiNakamura, 2018-03-05:
Even if we dont go with this architecture we still need a 2W rated SPDT switch

TobiNakamura, 2018-03-20:
@Alenux55 added SKY13345-368LF in conjunction with CD4555B to replace the diplexer.
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

TobiNakamura, 2018-03-20:
@Alenux55 What do you think about using Q3 as an error output?

Alenux55, 2018-03-20:
Like to display it on an LED?

Alenux55, 2018-04-17:
@TobiNakamura I am going to close this unless we can think of something to use for the extra outputs

Alenux55, 2018-04-20:
Closing.

Closed 2018-04-20.

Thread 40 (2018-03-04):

Add RF shielding to PA

TobiNakamura, 2018-03-04:
We currently have stock of these https://www.digikey.ca/product-detail/en/laird-technologies-emi/BMI-S-101/903-1006-1-ND/2175956 that was never used.

Alenux55, 2018-04-17:
Added a different [set of shields](https://www.digikey.ca/products/en?keywords=903-1054-1-ND)

Closed 2018-04-17.

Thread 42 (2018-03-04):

Find a better potentiometer

TobiNakamura, 2018-03-04:
Our current SMD pot breaks too easily.
Find a rugged through hole one

Alenux55, 2018-04-18:
Let's go with [CT6EP103-ND](https://www.digikey.ca/products/en?keywords=CT6EP103-ND)

Alenux55, 2018-04-18:
Added to design

Closed 2018-04-18.

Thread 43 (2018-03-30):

Fix the PA BOM matches the RFMD evaluation board, NOT the RF6886 datasheet

Alenux55, 2018-03-30:
Noticed some discrepancies between the RF6886 datasheet components and those specified in the BOM we received from Qorvo for the RF6886 evaluation board. Update the PA schematics (both bands) so that the parts match the RF6886 evaluation board BOM

Alenux55, 2018-03-30:
Complete the "[PA Component Comparison](https://docs.google.com/spreadsheets/d/11h_-MVh9ecNUfdz8JPoKIFBlfTD5eDK_UhkUIJyvaoE/edit#gid=0)" spreadsheet on the Drive at Subsystems/RF/Mark 3 - Post-Production Build

Alenux55, 2018-04-04:
PA LB issues:
- C417 (C17) should be after the series inductor; it is currently before the inductor; added an extra capacitor to both bands to fix this
- C413 and C422 (C1 and C9) were [100 pF](https://www.digikey.ca/products/en?keywords=490-5922-1-ND); changed to [39 pF](https://www.digikey.ca/products/en?keywords=490-5871-1-ND) (also used in the upper band
- Changed the Tantalum capacitor symbols to be polarized
- Making C411 DNP

PA UB issues:
- Making C511 DNP

Closed 2018-04-04.

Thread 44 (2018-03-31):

add connectors for the separation switches

TobiNakamura, 2018-03-31:
1 high current connector on the +y, -x corner
1 high current connector on the -y, +x corner

Closed 2018-04-24.

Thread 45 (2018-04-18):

Invert the LB switch controls to ease routing

Alenux55, 2018-04-18:
Currently, the LB switch orientation and the RF output switch orientation forces the RF paths to cross:
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

Add an inverter to the LB switch control signal so that we don't need to cross the signals

Alenux55, 2018-04-18:
From the SKY13372-467LF [datasheet](http://www.skyworksinc.com/uploads/documents/SKY13372_467LF_201443E.pdf) and with a 3.3 V supply, the maximum logic low is **1 V** and the minimum logic high is **2.3 V**; [74LVC1G14SE-7CT-ND](https://www.digikey.ca/products/en?keywords=74LVC1G14SE-7CT-ND) will work.

Alenux55, 2018-04-18:
Added the inverter and swapped the outputs B1 and B2 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

Alenux55, 2018-04-20:
@TobiNakamura looks good

Closed 2018-04-20.

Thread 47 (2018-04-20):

Clear space for Antenna Feed Cable assembley

TobiNakamura, 2018-04-20:
Space between the RF board and the antenna feed board is tight. The height of the SMA jack and SMA right angle connectors together are going to be tall and therefore need special accommodation on the board.

Draw the locations of interest on the fab layer.

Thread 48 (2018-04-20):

Comply with PCBway min mask width

TobiNakamura, 2018-04-20:
minimum solder mask width: 150um
Check all components.
Change mask setting on board or in footprint library?

TobiNakamura, 2018-04-26:
PCBWay_Fab.txt has been updated

Closed 2018-04-26.

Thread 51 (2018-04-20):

Place silkscreen

Alenux55, 2018-04-20:

Alenux55, 2018-09-16:
Not quite sure this issue is relevant anymore

Alenux55, 2018-09-20:
Board is done, so it's definitely done...

Closed 2018-09-20.

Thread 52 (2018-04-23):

Impedance Controlled Trace Clearance

TobiNakamura, 2018-04-23:
Current microstrip geometry: 0.2mm space, 0.336mm width
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

The space to ground should be 0.3mm according to the calculation. However, a 0.3mm clearance cannot be assigned to either the RF net class or the ground pour due to small SMD pitch.
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

We can either:
1. Create a large no fill zone around the RF net class and use the microstrip instead of a coplanar wave guide.
2. Maintain 0.2mm clearance and modify trace width to 0.315313mm
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

TobiNakamura, 2018-04-27:
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
Microstrip trace width set to 0.321mm.
Controlling distance to copper fill is complicated due to the dimention requirements near IC pads. Therefore keepout ares will be used around the microstip.

Closed 2018-04-27.

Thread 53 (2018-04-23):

Remove OP_3v3 jumper

TobiNakamura, 2018-04-23:
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
This feature make the power plane more complex. We can remove it and connect VDD to the main 3v3 rail. If the debugger is to provide power you can apply it directly to the 3v3 pin in the PC104 bus.

Alenux55, 2018-04-24:
Are we able to turn off the debugger's output power? If not, do we anticipate never needing to control the board with the CC debugger and powering it from the PC104 stack?

TobiNakamura, 2018-04-24:
http://www.ti.com/lit/ug/swru197h/swru197h.pdf
Schematic on appendix A. Pin 9 of the CC-Debugger header is permanently connected to 3v3.
I think the only use case for the CC-debugger is initial bring-up. So probing the CC1101 output.

TobiNakamura, 2018-04-26:
Pin 9 (OP_3.3) has been disconnected. 3.3v net of CC1101.sch now connected to board wide 3V3 net.

Closed 2018-04-26.

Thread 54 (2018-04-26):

Manual Gain Control

TobiNakamura, 2018-04-26:
Gain control using the potentiometer should vary the output between 0 and 3.1V.
This can be done linearly using only a potentiometer, however we are only interested in using the circuit with an output above ~2V. A non-linear circuit can be constructed to maximise the resolution around the desired output voltage.
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
Note R411 and R412 exists to replace the potentiometer in case a fixed value is desired.

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
The x-axis is the fraction of wiper position along the length of the rail, y is the output voltage. The non-linearity of the output can be controlled using R_2. I suggest we use R_2 = 100k ohms.

TobiNakamura, 2018-04-27:
100k 0402 res added

Alenux55, 2018-09-20:
Done.

Closed 2018-09-20.

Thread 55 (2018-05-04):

Upper Band Balun and Filter Needs Redesign

TobiNakamura, 2018-05-04:
Currently we are using Johanson Tech. 0915BM15A0001E integrated balun and filter (Center freq 915MHz). The required center frequency is 790MHz.

Alenux55, 2018-09-27:
IIRC we want the center frequency around 790 MHz

Alenux55, 2018-10-02:
How about [0783FB15A0100E](https://www.digikey.ca/products/en?keywords=712-1537-1-ND) filterbalun and match it to the CC1101? See CC1101 [Design Note DN017](http://www.ti.com/lit/an/swra168a/swra168a.pdf) as well:
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

TobiNakamura, 2018-10-02:
Good idea.
Per [DN017 (swra168a)](http://www.ti.com/lit/an/swra168a/swra168a.pdf) the differential impedance at the CC1101 port looking towards the antenna is  Z= 86.5 + j43 Ohm at 868/915 MHz.

Alenux55, 2018-10-02:
I will see if TI happens to have the impedance data for 700-800 MHz

Alenux55, 2018-10-04:
[TI post](https://e2e.ti.com/support/wireless-connectivity/sub-1-ghz/f/156/t/733964)

Alenux55, 2018-10-08:
TI suggests two alternative filter baluns, the claim is that we only lose 0.25 dB extra gain to insertion loss

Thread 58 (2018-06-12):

Change the gain resistors

Alenux55, 2018-06-12:
Replace R405 & R406 with 56k and R407 & R408 with 287R (Same for R50*)

Closed 2018-06-12.

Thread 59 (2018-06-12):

Replace LED Current limiting res with array

TobiNakamura, 2018-06-12:
https://www.digikey.ca/products/en/resistors/resistor-networks-arrays/50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

Alenux55, 2018-09-20:
I think it's just as easy to use individual resistors, and more options for alternatives. More interested in consolidating BOM line items than quantity

Closed 2018-09-20.

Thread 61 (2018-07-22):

Whole system disable

TobiNakamura, 2018-07-22:
external pin to disable the 3v3 power plane on the rf board.
Part of the RF inhibit feature

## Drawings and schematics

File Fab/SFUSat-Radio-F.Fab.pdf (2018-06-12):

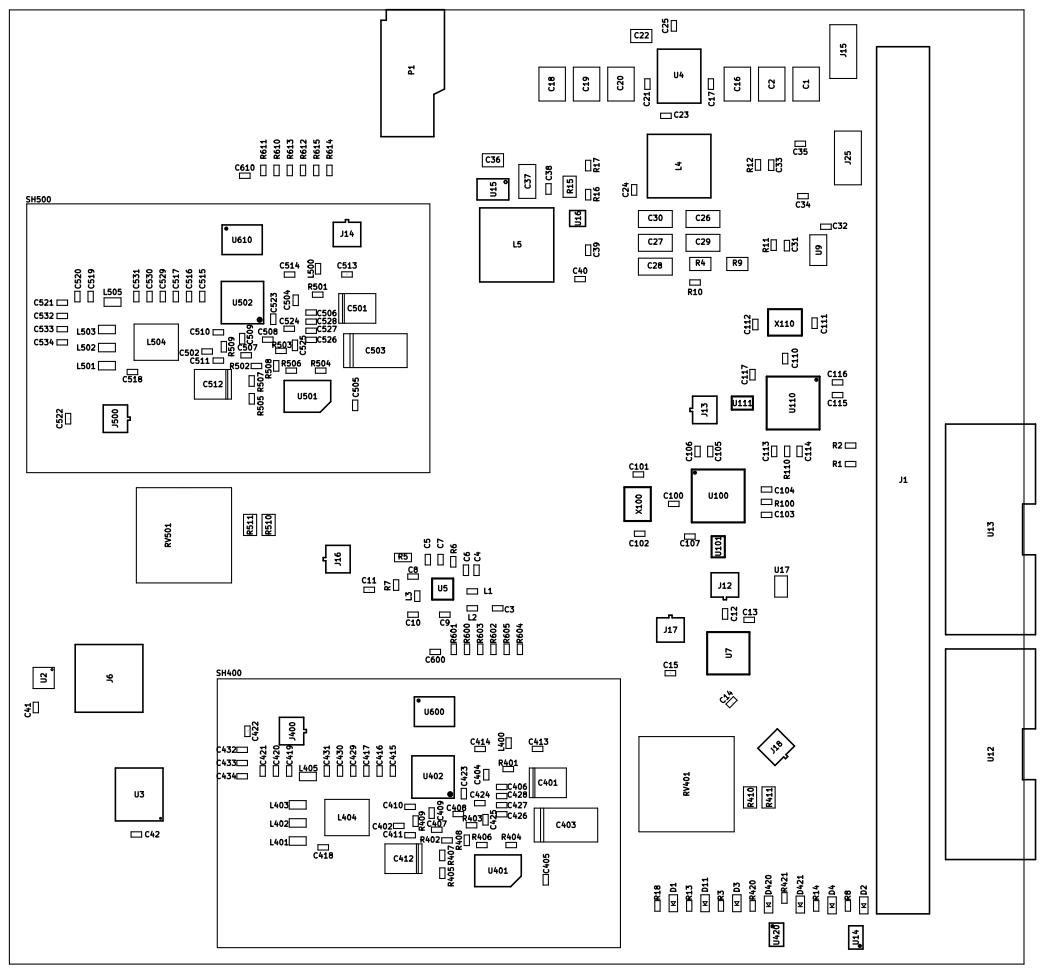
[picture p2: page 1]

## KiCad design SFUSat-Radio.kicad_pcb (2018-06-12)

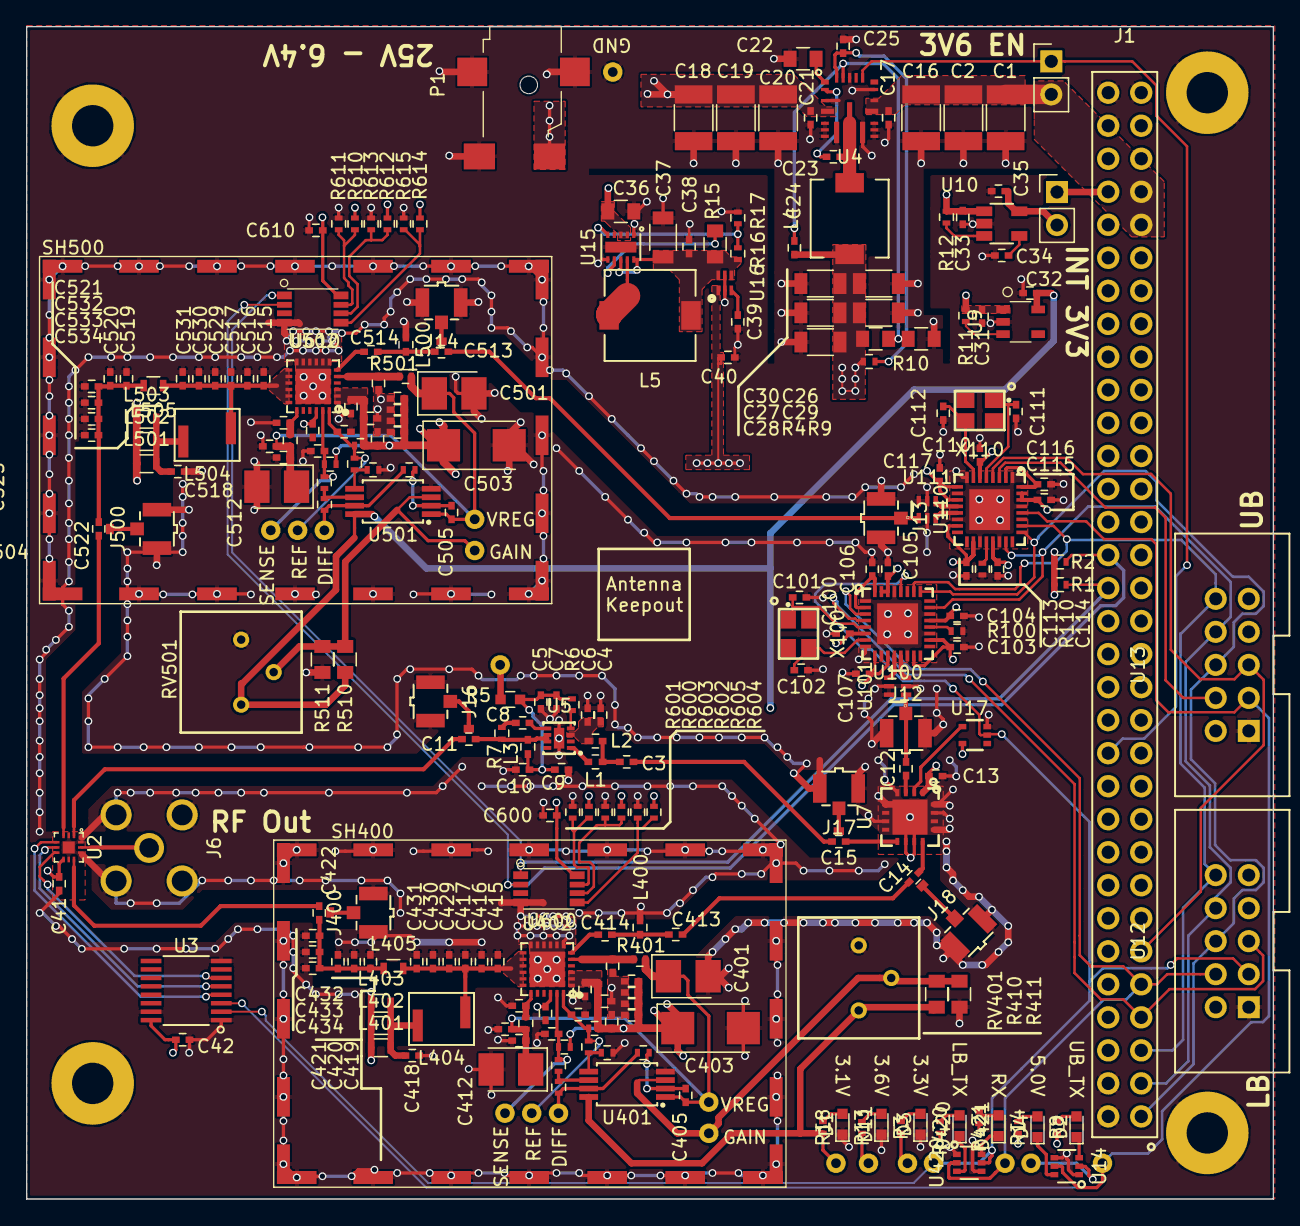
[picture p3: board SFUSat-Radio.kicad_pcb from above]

Board: 4 copper layers, 95.9 x 90.2 mm, 280 parts (0 on the bottom side), 120 nets.

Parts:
C1, C2, C16, C18, C19, C20: 10uF; C_1210
C3, C11: 100pF; C_0402
C4, C9: 390pF; C_0402
C5, C6: 0.01uF; C_0402
C7, C8: 56pF; C_0402
C10: 0.1uF; C_0402
C12, C14, C15: 47pF; C_0402
C13: 47nF; C_0402
C17, C21: 1nF; C_0402
C22: 4.7uF; C_0805
C23: 470nF; C_0402
C24: 680pF; C_0402
C25, C33, C38, C41, C42, C100, C103, C105, C106, C107, C110, C113, C115, C116, C117: 100nF; C_0402
C26, C27, C28, C29, C30: 47uF; C_1206
C31, C32, C40, C402, C407, C408, C409, C502, C507, C508, C509: 1uF; C_0402
C34, C411, C415, C416, C423, C424, C425, C426, C427, C428, C429, C430, C431, C432, C433, C434, C511, C519, C523, C524, C525, C526, C527, C528, C529, C530, C531, C532, C533, C534, C600, C610: DNP; C_0402
C35, C404, C410, C418, C504, C510: 2.2uF; C_0402
C36: 2.2uF; C_0805
C37: 22uF; C_1206
C39: 10nF; C_0402
C101, C111, C516: 12pF; C_0402
C102, C112, C515: 15pF; C_0402
C104, C114, C406, C506: 220pF; C_0402
C401, C412, C501, C512: 10uF; C_TANT_1411
C403, C503: 10uF; C_TANT_2312
C405, C505: 0.33uF; C_0402
C413, C422, C513, C522: 39pF; C_0402
C414: 22pF; C_0402
C417, C420, C517: 10pF; C_0402
C419, C518: 27pF; C_0402
C421: 1.2pF; C_0402
C514: 7.5pF; C_0402
C520: 5.6pF; C_0402
C521: 0.5pF; C_0402
D1, D2, D3, D4, D11, D420, D421: GREEN; LED_0603
J1: PC104-8BIT; PC104-8bit
J2, J3, J4, J5: PC104PTH
J6: SMA; SMA-Vert-TH
J7, J8, J9, J10, J11, J21, J22, J23, J24, J401, J402, J404, J405, J406, J501, J502, J504, J505, J506: TP_TH_150
J12, J13, J14, J16, J17, J18, J400, J500: SMA; UFL-R-SMT-1-Coaxial-Connector
J15, J25: Conn_01x02; Socket_Strip_Straight_1x02_Pitch2.54mm
L1: 22nH; L_0402
L2: 4.3nH; L_0402
L3: 24nH; L_0402
L4: 10uH; SLF6045
L5: 10uH; SLF7045
L400: 8.2nH; L_0402
L401, L402, L403, L405: 0R0; L_0603
L404: 12.55nH; L_1606
L500: 2.7nH; L_0402
L501, L502: 220R; L_0603
L503: DNP; L_0603
L504: 5.6nH; L_1606
L505: 1.5nH; L_0603
P1: 3pin-DC-power; PJ-028-SMT-TR-3pin-DC-jack
R1, R2: 1k0-DNP; R_0402
R3, R8, R13, R14, R18, R420, R421: 287; R_0402
R4: 49k9; R_0805
R5: 0R05; C_0603
R6: 1210; R_0402
R7: 100; R_0402
R9: 19K1; R_0805
R10: 3.01R; R_0402
R11, R404, R504: 1K; R_0402
R12: 1k; R_0402
R15, R410, R510: 100k; R_0805
R16: 2.37M; R_0402
R17: 383k; R_0402
R100, R110: 56k; R_0402
R401, R409, R501, R509: 220R; R_0402
R402, R403, R502, R503: 390R; R_0402
R405, R406, R407, R408, R505, R506, R507, R508: 10K; R_0402
R411, R511: DNP; R_0805
R600, R603, R605, R611, R612, R615: 0R; R_0402
R601, R602, R604, R610, R613, R614: DNP; R_0402
RV401, RV501: CT6EP103
SH400, SH500: BMI-S-205-F
U1, U6, U8, U11, U400, U500: SINGLE_0402
U2: SKY13345-368LF; 12-UFQFN-PAD
U3: CD4555BPWR; TSSOP-16
U4: LMS3635AQRNLRQ1; LMS3635AQRNLTQ1
U5: MML09211H; 8-VFDFN
U7: SKY13372-467LF; QFN-16_650P
U9: TLV702; SOT_23_5
U10: TPS799; PDSO-G5
U12, U13: CONN_02X05_SHRD; Socket_Strip_Straight_2x05
U14, U420: 2N7002DW; SOT-363
U15: TPS62175DQCR; WSON-10
U16: TPS71750DSER; WSON-6
U17: 74LVC1G14SE-7; SOT353
U100, U110: CC1101-Q1
U101: 0433BM15A0001; U_0805-6
U111: 0915BM15A0001E; U_0805-6
U401, U501: LMV358; TSSOP-8_4.4x3mm_Pitch0.65mm
U402, U502: RF6886; QFN-24
U600, U610: STLM75; TSSOP-8-3x3mm-SOT505-1
X100, X110: NX3225GA

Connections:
/3.3V Regulator/3V3OUT: C35.1, J25.2, U10.5
/3.6V Regulator/BIAS: C25.1, R10.1, U4.22
/3.6V Regulator/BOOST: C23.1, U4.2
/3.6V Regulator/FB: C24.2, R4.2, R9.1, U4.21
/3.6V Regulator/SW: C23.2, L4.1, U4.9
/3V1: C32.1, J9.1, R18.1, R410.1, R510.1, RV401.1, RV501.1, U9.5, U401.8, U501.8
/3V3: C13.1, C41.1, C42.1, C100.2, C103.2, C104.2, C105.2, C107.2, C110.2, C113.2, C114.2, C115.2, C117.2, C600.1, C610.1, J1.3B, J1.29B, J8.1, J25.1, R1.1, R2.1, R3.1, R8.1, R14.1, R420.1, R421.1, R600.1, R602.1, R604.1, R610.1, R612.1, R614.1, U2.7, U3.16, U7.1, U12.2, U13.2, U17.5, U100.6, U100.9, U100.11, U100.15, U100.18, U100.21, U100.30, U100.31, U110.6, U110.9, U110.11, U110.15, U110.18, U110.21, U110.30, U110.31, U600.8, U610.8
/3V6: C24.1, C26.1, C27.1, C28.1, C29.1, C30.1, C31.1, C33.1, C403.1, C406.1, C409.1, C423.1, C424.1, C425.1, C426.1, C427.1, C428.1, C503.1, C506.1, C509.1, C523.1, C524.1, C525.1, C526.1, C527.1, C528.1, J7.1, L4.2, L401.1, L402.1, L403.1, L501.1, L502.1, L503.1, R4.1, R10.2, R11.1, R12.2, R13.1, R402.2, R403.2, R502.2, R503.2, U9.1, U10.1, U402.1, U402.2, U402.3, U402.22, U502.1, U502.2, U502.3, U502.22
/5V0: C40.1, J10.1, J24.1, R5.1, U14.2, U16.1
/5V Regulator/5V8: C37.1, C38.1, L5.2, R15.1, R16.1, U15.8, U15.10, U16.4, U16.6
/5V Regulator/SW_5V8: L5.1, U15.9
/CC1101_LB/RF_N: U100.13, U101.3
/CC1101_LB/RF_P: U100.12, U101.4
/CC1101_UB/GDO0: U13.4, U110.3
/CC1101_UB/RF_N: U110.13, U111.3
/CC1101_UB/RF_P: U110.12, U111.4
/EN_3V6: J1.12B, J15.1, U4.18
/LB_HP_RX: C11.1, U2.1
/LB_HP_TX: C422.1, U2.9
/LB_LP: C12.1, J12.1, U101.1
/LB_LP_RX: C3.2, C15.1
/LB_LP_TX: C14.1, C413.2
/LB_RX0TX1: J21.1, U3.2, U12.3, U17.2, U100.28, U420.5
/LB_TEST_TX: C419.1, C420.1, C421.1, C422.2, C432.1, C433.1, C434.1, L405.1
/MISO: J1.3A, U12.10, U13.10, U100.26, U110.26
/MOSI: J1.2A, U12.8, U13.8, U100.23, U110.23
/PA_LB/GAIN: J406.1, R410.2, R411.1, RV401.2, U401.3
/PA_LB/IN: C414.1, U402.6
/PA_LB/OUT: C415.1, C416.1, C417.1, C429.1, C430.1, C431.1, L404.2, L405.2, U402.13, U402.14, U402.15, U402.16, U402.17, U402.18
/PA_LB/PWR_REF: C408.1, J405.1, R403.1, R408.1, U402.24
/PA_LB/PWR_SENSE: C407.1, J404.1, R402.1, R407.1, U402.23
/PA_LB/VREG: C401.1, C402.1, C405.2, C411.1, C412.1, J401.1, R401.2, R409.1, U401.1
/PA_UB/GAIN: J506.1, R510.2, R511.1, RV501.2, U501.3
/PA_UB/IN: C514.1, U502.6
/PA_UB/OUT: C515.1, C516.1, C517.1, C529.1, C530.1, C531.1, L504.2, L505.1, U502.13, U502.14, U502.15, U502.16, U502.17, U502.18
/PA_UB/PWR_REF: C508.1, J505.1, R503.1, R508.1, U502.24
/PA_UB/PWR_SENSE: C507.1, J504.1, R502.1, R507.1, U502.23
/PA_UB/VREG: C501.1, C502.1, C505.2, C511.1, C512.1, J501.1, R501.2, R509.1, U501.1
/PKT_RCV: J1.5A, J22.1, U12.4, U100.3, U420.2
/SCL: J1.18B, R2.2, U600.2, U610.2
/SCLK: J1.1A, U12.6, U13.6, U100.25, U110.25
/SDA: J1.17B, R1.2, U600.1, U610.1
/Temp_sense_LB/A0: R600.2, R601.1, U600.7
/Temp_sense_LB/A1: R602.2, R603.1, U600.6
/Temp_sense_LB/A2: R604.2, R605.1, U600.5
/Temp_sense_UB/A0: R610.2, R611.1, U610.7
/Temp_sense_UB/A1: R612.2, R613.1, U610.6
/Temp_sense_UB/A2: R614.2, R615.1, U610.5
/UB_HP_TX: C522.1, U2.3
/UB_LP: C513.2, J13.1, U111.1
/UB_RX0TX1: J23.1, U3.3, U13.3, U14.5, U110.28
/UB_TEST_TX: C519.1, C520.1, C521.1, C522.2, C532.1, C533.1, C534.1, L505.2
/V1: U2.4, U3.4
/V2: U2.5, U3.5
/V3: U2.6, U3.6
/VIN: C1.1, C2.1, C16.1, C17.1, C18.1, C19.1, C20.1, C21.1, C36.1, J1.28A, J1.29A, J15.2, P1.1, U4.4, U4.14, U4.15, U15.2, U15.3
/~LB_CS: J1.4A, U12.5, U100.4
/~UB_CS: J1.6A, U13.5, U110.4
GND: C1.2, C2.2, C4.2, C5.2, C6.2, C7.2, C9.2, C10.2, C13.2, C16.2, C17.2, C18.2, C19.2, C20.2, C21.2, C22.2, C25.2, C26.2, C27.2, C28.2, C29.2, C30.2, C31.2, C32.2, C33.2, C34.2, C35.2, C36.2, C37.2, C38.2, C39.2, C40.2, C41.2, C42.2, C100.1, C101.1, C102.1, C103.1, C104.1, C105.1, C106.2, C107.1, C110.1, C111.1, C112.1, C113.1, C114.1, C115.1, C116.2, C117.1, C401.2, C402.2, C403.2, C404.2, C406.2, C407.2, C408.2, C409.2, C410.2, C411.2, C412.2, C415.2, C416.2, C417.2, C418.1, C419.2, C420.2, C421.2, C423.2, C424.2, C425.2, C426.2, C427.2, C428.2, C429.2, C430.2, C431.2, C432.2, C433.2, C434.2, C501.2, C502.2, C503.2, C504.2, C506.2, C507.2, C508.2, C509.2, C510.2, C511.2, C512.2, C515.2, C516.2, C517.2, C518.1, C519.2, C520.2, C521.2, C523.2, C524.2, C525.2, C526.2, C527.2, C528.2, C529.2, C530.2, C531.2, C532.2, C533.2, C534.2, C600.2, C610.2, D1.1, D3.1, D11.1, J1.1B, J1.2B, J1.31B, J1.32A, J1.32B, J2.1, J3.1, J4.1, J5.1, J6.2, J11.1, J12.2, J13.2, J14.2, J16.2, J17.2, J18.2, J400.2, J500.2, L400.2, L500.2, P1.2, P1.3, R9.2, R17.2, R100.2, R110.2, R406.2, R411.2, R506.2, R511.2, R601.2, R603.2, R605.2, R611.2, R613.2, R615.2, RV401.3, RV501.3, SH400.1, SH400.2, SH400.3, SH400.4, SH400.5, SH400.6, SH400.7, SH400.8, SH400.9, SH400.10, SH400.11, SH400.12, SH400.13, SH400.14, SH400.15, SH400.16, SH400.17, SH400.18, SH400.19, SH400.20, SH500.1, SH500.2, SH500.3, SH500.4, SH500.5, SH500.6, SH500.7, SH500.8, SH500.9, SH500.10, SH500.11, SH500.12, SH500.13, SH500.14, SH500.15, SH500.16, SH500.17, SH500.18, SH500.19, SH500.20, U2.2, U2.8, U2.10, U2.12, U2.13, U3.1, U3.8, U3.15, U4.3, U4.5, U4.6, U4.7, U4.8, U4.10, U4.11, U4.12, U4.13, U4.16, U4.20, U5.9, U7.4, U7.5, U7.6, U7.7, U7.8, U7.10, U7.11, U7.13, U7.14, U7.15, U7.16, U7.17, U9.2, U10.2, U12.1, U13.1, U14.1, U14.4, U15.1, U15.6, U15.EP, U16.2, U16.5, U17.3, U100.1, U100.8, U100.10, U100.14, U100.19, U100.22, U100.29, U100.33, U101.2, U101.5, U101.6, U110.1, U110.8, U110.10, U110.14, U110.19, U110.22, U110.29, U110.33, U111.2, U111.5, U111.6, U401.4, U402.7, U402.8, U402.9, U402.10, U402.11, U402.12, U402.CP, U420.1, U420.4, U501.4, U502.7, U502.8, U502.9, U502.10, U502.11, U502.12, U502.CP, U600.4, U610.4
unnamed: C3.1, L1.1, L2.2
unnamed: C4.1, C6.1, L1.2, U5.3
unnamed: C8.1, R7.2
unnamed: C8.2, U5.5
unnamed: C5.1, C7.1, C9.1, C10.1, L3.1, R5.2, R6.1
unnamed: C11.2, L3.2, R7.1, U5.6, U5.7
unnamed: C12.2, U7.3
unnamed: C14.2, U7.12
unnamed: C15.2, U7.9
unnamed: C22.1, U4.1
unnamed: C34.1, U10.4
unnamed: C39.1, U16.3
unnamed: C101.2, U100.5, X100.1
unnamed: C102.2, U100.7, X100.3
unnamed: C106.1, U100.2, U100.32
unnamed: C111.2, U110.5, X110.1
unnamed: C112.2, U110.7, X110.3
unnamed: C116.1, U110.2, U110.32
unnamed: C404.1, R401.1, U402.5
unnamed: C405.1, R404.2, U401.2
unnamed: C410.1, R409.2, U402.19
unnamed: C413.1, C414.2, L400.1
unnamed: C418.2, L401.2, L402.2, L403.2, L404.1
unnamed: C504.1, R501.1, U502.5
unnamed: C505.1, R504.2, U501.2
unnamed: C510.1, R509.2, U502.19
unnamed: C513.1, C514.2, L500.1
unnamed: C518.2, L501.2, L502.2, L503.2, L504.1
unnamed: D1.2, R18.2
unnamed: D2.1, U14.3
unnamed: D2.2, R8.2
unnamed: D3.2, R3.2
unnamed: D4.1, U14.6
unnamed: D4.2, R14.2
unnamed: D11.2, R13.2
unnamed: D420.1, U420.3
unnamed: D420.2, R420.2
unnamed: D421.1, U420.6
unnamed: D421.2, R421.2
unnamed: J6.1, U2.11
unnamed: J14.1, U1.1
unnamed: J16.1, U6.1
unnamed: J17.1, U11.1
unnamed: J18.1, U8.1
unnamed: J400.1, U400.1
unnamed: J402.1, R404.1, R405.2, U401.7
unnamed: J500.1, U500.1
unnamed: J502.1, R504.1, R505.2, U501.7
unnamed: L2.1, U5.1
unnamed: R6.2, U5.4
unnamed: R11.2, U9.3
unnamed: R12.1, U10.3
unnamed: R15.2, U15.7
unnamed: R16.2, R17.1, U15.5
unnamed: R100.1, U100.20
unnamed: R110.1, U110.20
unnamed: R405.1, R407.2, U401.6
unnamed: R406.1, R408.2, U401.5
unnamed: R505.1, R507.2, U501.6
unnamed: R506.1, R508.2, U501.5
unnamed: U7.2, U17.4

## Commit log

2017-01-03 took out the mcu schematic, fixed transciever for separate tx rx ports
    [SFUSat-Radio.sch, Transceiver.sch]
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2017-01-04 added Vdd pins to Transciever and amplifier modules
    [_saved_Front_End.sch, _saved_SFUSat-Radio.sch, _saved_Transceiver.sch]
2017-01-07 deleted MCU schematic for v0.1. Added power sub-schematic
    [Front_End.sch, MCU.sch, SFUSat-Radio.sch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]
2017-01-08 added SKY65366-21 schematic and footprint to library. Populated front end schematic with SKY and peripherial components. Added 3V6 output for power sub-schematic.
    [Front_End.sch, Power.sch, SFUSat-Radio.sch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]
2017-01-08 added BALF-112X-02D3 to component library and to transciever sub-schematic
    [SFUSat-Radio.sch, Transceiver.sch]
2017-01-09 Added RF switch to transciever schematic
    -Removed SMA lib pointing to Tobi's downloads
    -Added SKY13372-467LF to the library (symbol and decal)
    -Renamed signal “TX_SW” on RF front end page to “TRX_SIG”
    -Re-aligned some part names and reference designators
    -Added some component values to the front end
    [Front_End.sch, SFUSat-Radio.sch, Transceiver.sch]
2017-01-09 Added XOSC
    -Changed the VDD pin of the RF switch to a power input
    -Added the XOSC (symbol and footprint)
    -Made some modifications to the transceiver page
    [Transceiver.sch]
2017-01-10 Fixed XOSC
    -Changed 3V3 rail of XOSC to 1V8 as specified in datasheet
    -Changed XOSC capacitor values to match the datasheet
    -Added 1V8 rail to SFUSat-Radio.sch Transceiver and Power pages
    [Power.sch, SFUSat-Radio.sch, Transceiver.sch]
2017-01-12 added jumpers for regulater EN and a jumper for fixing PA_ADJ. Connceted TRX_SIG to GPIO0
    [SFUSat-Radio.sch, Transceiver.sch]
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2017-01-15 added switches for various option and nmos array to control status leds
    [Front_End.sch, Power.sch, SFUSat-Radio.sch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]
2017-01-15 added a bunch of footprints and generated layout file
    [Front_End.sch, Power.sch, SFUSat-Radio.sch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]
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2017-01-16 project files till workbut names are messed up
    [Transceiver.sch, _saved_Front_End.sch, _saved_Transceiver.sch]
2017-01-19 fixed filesystem
    [Front_End.sch, SFUSat-Radio.kicad_pcb, SFUSat-Radio.sch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]
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2017-01-23 Checked changes from botched commit
    -R5 and R6 are gone as desired
    -C4 changed from 10 nF to 100 nF looks good
    -Split up nets between pins 27 and 28 so each have their own dedicated
    capacitor
    -Added C9 to pin 28 and forward annotated it into the layout
    [Front_End.sch, Power.sch, SFUSat-Radio.kicad_pcb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]
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2017-01-24 Mirrored changes from "Replaced XOSC" (fdb08e0)
    -Changed value of C5 from 10nF to 1nF
    -Added 0 ohm jumper R4 to XOSC supply rail
    -Added C13 to separate decoupling caps on pins 27 and 28
    -Added C33 to separate decoupling caps on pins 12 and 13
    -Forward annotated changes
    [Front_End.sch, Power.sch, SFUSat-Radio.kicad_pcb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]
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2017-01-25 trace width changed with coplanar waveguide calculations in mind
    [SFUSat-Radio.kicad_pcb]
2017-01-26 fixed rf track to match coplanar calculations, added ground vias
    [SFUSat-Radio.kicad_pcb]
2017-01-26 Swapped capacitor footprints
    -Changed C27 and C37 from 0402 to 0603_HandSoldering
    -Changed C34 and C39 from 0402 to 1210_HandSoldering
    [Front_End.sch, Power.sch, SFUSat-Radio.kicad_pcb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]
2017-01-26 added back side copper to edge mounted sma footprint
    [SFUSat-Radio.kicad_pcb]
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2017-01-30 changed via in pad to 10mil drill hole
    [SFUSat-Radio.kicad_pcb]
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2017-02-01 fixed soldermask on CC1125
    [SFUSat-Radio-B.Cu.gbr, SFUSat-Radio-B.Mask.gbr, SFUSat-Radio-B.SilkS.gbr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]
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2017-02-02 moved via in pad to avoid stencil aperture, added pin 1 markers to a few footprints
    [SFUSat-Radio-B.Cu.gbr, SFUSat-Radio-B.Mask.gbr, SFUSat-Radio-B.SilkS.gbr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]
2017-02-03 Added pull ups
    1K pull ups added on EN of DC-DC regulators and EN of front -end
    [Front_End.sch, Power.sch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]
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2017-02-03 Fixed component ref
    [SFUSat-Radio.kicad_pcb]
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2017-05-11 added reset tactile switch
    [Front_End.sch, Power.sch, SFUSat-Radio.sch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]
2017-05-12 Deleted the PCB and annotated the schematic
    Since we're going to be using a new XCVR IC, we need to re-design the PCB
    [Front_End.sch, Power.sch, SFUSat-Radio.kicad_pcb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]
2017-05-22 Added CC1101 balun, updated README.md
    Added a note to the 'README.md' file explaining how to properly clone and set up the KiCad library submodule
    [_saved_Transceiver.sch]
2017-05-22 Forgot to save before I committed the balun
    [Front_End.sch, Power.sch, SFUSat-Radio.sch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]
2017-05-23 added CC1101, fixed mission symbols
    [Front_End.sch, Power.sch, SFUSat-Radio.sch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]
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2017-05-27 fixed rescue library
    [Front_End.sch, Power.sch, SFUSat-Radio.sch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]
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2017-05-28 Added CC1101-Q1 and supporting components
    Also added the pad that routes to the SMA for RF path testing
    [CC1101EM_434MHz_PARTLIST_2_0_0.xls, Front_End.sch, Power.sch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]
2017-05-28 Removed SW1
    CC1101-Q1 has no reset pin, so no point in having a reset switch
    [SFUSat-Radio.sch]
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2017-05-31 pulled SKY en high, replaced BYP with jump
    [Front_End.sch]
2017-05-31 Updated schematic and layout
    Added extra decoupling caps based on TI feedback and forward annotated changes to the PCB
    [Front_End.sch, Power.sch, SFUSat-Radio.kicad_pcb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]
2017-05-31 Changed C25 and C26 from 0.1uF to 100nF
    [Front_End.sch, Power.sch, SFUSat-Radio.sch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]
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2017-06-02 all leds green, fixed VPC ctrl
    [Front_End.sch, Power.sch, SFUSat-Radio.sch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]
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2017-06-09 fixed 3v3 reg footprint
    [Front_End.sch, SFUSat-Radio.kicad_pcb, SFUSat-Radio.sch]
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2017-06-10 fixed labels, via stitching
    [Front_End.sch, SFUSat-Radio.kicad_pcb]
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2017-06-10 IC->passive pad 30mil clearance
    [Front_End.sch, Power.sch, SFUSat-Radio.kicad_pcb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]
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2017-06-11 fixed microstrip
    [SFUSat-Radio-B.Cu.gbr, SFUSat-Radio-Edge.Cuts.gbr, SFUSat-Radio-F.Cu.gbr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]
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2017-06-12 gerber fixes
    [SFUSat-Radio-B.Cu.gbr, SFUSat-Radio-Edge.Cuts.gbr, SFUSat-Radio-F.Cu.gbr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]
2017-06-12 fixed CC1101 stencil
    [SFUSat-Radio.kicad_pcb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]
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2017-12-25 Added 3D models for J6 and J1. See Kicad-Lib commit c9457c5d894628088f6aa1cc63c8179390a49ea0 for more detail.
    [SFUSat-Radio.kicad_pcb]
2018-01-12 Added PA, Diplexer, and LNA schematics. All three were copied over from the Amp_dev project. The PA and LNA schematics need extensive work.
    [Diplexer.sch, Front_End.sch, LNA.sch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]
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2018-01-12 Added note on microstrip width. Calculated according to the stackup as provided in PCBWay_fab.txt
    [Diplexer.sch, Front_End.sch, LNA.sch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]
2018-01-19 Added new sheets
    Started adding hierarchical sheets for high and low band components
    [Diplexer.sch, HB_PA.sch, LB_PA.sch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]
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2018-03-02 Replaced SMA with u.fl for debug ports
    [Diplexer.sch, LB_PA.sch, LB_XCVR.sch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]
2018-03-05 consolidated PA to one sch for both bands
    [Diplexer.sch, HB_PA.sch, LB_PA.sch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]
2018-03-05 setup hierarchical sheets for transiever, SPDT switch, and PA. This configuration uses duplicate sheets to automate layout and ease schematic reading
    [CC1101.sch, Diplexer.sch, LB_XCVR.sch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]
2018-03-05 layed out upper band and lower band schematic. Need to add a 2W rated SPDT switch to connect the RX and TX stages together before the diplexer
    [CC1101.sch, LNA.sch, PA.sch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]
2018-03-05 Debug SPI port for CC1101 added to CC1101.sch
    [CC1101.sch, PA.sch, Power.sch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]
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2018-03-23 Fixed rescue-lib components and CONN_02X05
    [CC1101.sch, Diplexer.sch, LNA.sch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]
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2018-03-24 Changed temp sense reference designator prefix
    Initally overlapped with PA LB reference designator prefix
    [SFUSat-Radio.sch, TEMP_SENSE.sch]
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2018-03-30 Fixed the components for the PA LB section
    Fix the PA UB section next
    [PA.sch, Power.sch, SFUSat-Radio.kicad_pcb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]
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2018-04-04 Added extra DNP filter caps for PAs
    Also confirmed PA UB components and updated Google Sheet
    [PA.sch, SFUSat-Radio.kicad_pcb]
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2018-04-11 Fixed a couple DRCs
    [SFUSat-Radio.kicad_pcb]
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2018-04-23 layed out planes around regulator. The default clearance for poly was set to 1.27 mm but PCBway requires a minimum track spacing of 0.1524mm
    [Reg_3V1.sch, Reg_3V6.sch, SFUSat-Radio.kicad_pcb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]
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2018-04-24 fixed LB cc1101 test point
    [SFUSat-Radio.kicad_pcb]
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2018-04-26 changed clearance of all planes to 0.2mm. 0.1524mm is too close to PCBway's manufacturable limit
    [SFUSat-Radio.kicad_pcb]
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2018-04-27 modified gain control circuit in following issue #54
    [PA.sch, SFUSat-Radio.kicad_pcb]
2018-04-27 Changed microstrip width, added no fill zone around microstrip. Closes issue #52
    [SFUSat-Radio.kicad_pcb]
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2018-04-27 increased anti-pad clearance to 0.1524mm
    [SFUSat-Radio-B.Cu.gbr, SFUSat-Radio-B.Mask.gbr, SFUSat-Radio-B.SilkS.gbr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]
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2018-04-28 close issue #50
    [CC1101.sch, PA.sch, SFUSat-Radio.kicad_pcb]
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2018-05-04 fixed BoM
    [SFUSat-Radio-BoM.xlsx]
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2018-06-02 Updated components missing courtyard, assy dwgs., etc.
    [SFUSat-Radio.kicad_pcb]
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
